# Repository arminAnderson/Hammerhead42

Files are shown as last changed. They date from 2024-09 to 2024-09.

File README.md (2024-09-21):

# Hammerhead42
42 key board with 24 degree angled sides with 3key support

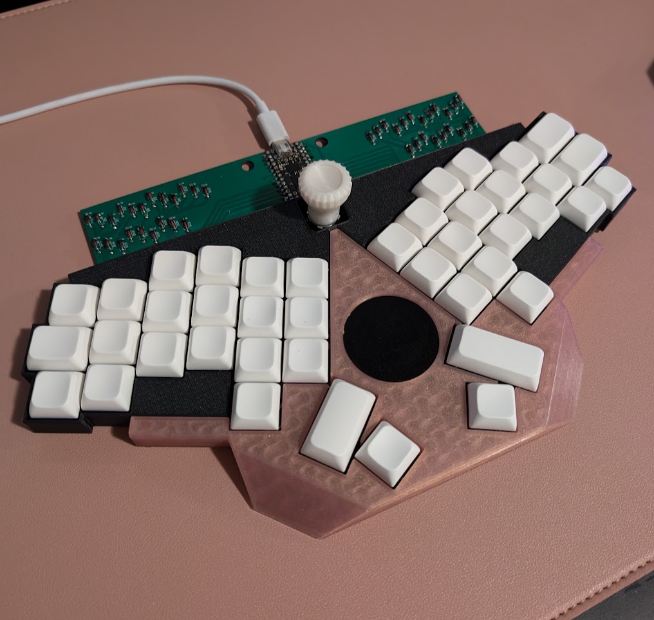
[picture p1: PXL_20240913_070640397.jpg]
Example


# Current required hardware
* M2 screws
* M2 threaded inserts (https://www.amazon.com/dp/B0D477R64K?ref=ppx_yo2ov_dt_b_fed_asin_title&th=1)
* RKJXT1F42001 (https://www.digikey.com/en/products/detail/alps-alpine/RKJXT1F42001/19529127, cap here: https://www.printables.com/model/1013994-rkjxt1f42001-cap)
* 40mm cirque touchpad (https://www.mouser.com/ProductDetail/Cirque/TM040040-2024-302?qs=wd5RIQLrsJgMzmw571gvDw%3D%3D)
* 4 wires (touchpad is handwired to a breakout)
* Helios or similar (https://keeb.supply/products/0xcb-helios)
* Rubber feet
* One set of 2u stabs for right hand side (optional)

# v0.9 (current)
* Now using PCB instead of handwire

# Fixes planned for 1.0
* Right now, the case uses printed washers to help pin the case to the pcb, and rubber feet on the bottom to keep the pcb off the desk. Originally I did this to keep the thickness as minimal as possible, but I'd like to design a 2 piece case with a bottom
* Some of the mounting holes for the case on the pcb are tenths of a mm off, which probably isn't even perceptible but I want to get those perfectly aligned 
* Cases without the RKJXT1F and/or trackpad
* A way to mount the trackpad without a full case
* Full build guide
* Multiple key configurations (all 1u, for example). Currently, the non-1u keys are
  * 1.25 tab
  * 1.5 \|
  * 1.5 enter
  * 1.75 shift (left thumb)
  * 2 space (right thumb)

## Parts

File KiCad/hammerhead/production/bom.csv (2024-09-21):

Designator | Footprint | Quantity | Value | LCSC Part #
D1, D10, D11, D12, D13, D14, D15, D16, D17, D18, D19, D2, D20, D21, D22, D23, D24, D25, D26, D27, D28, D29, D3, D30, D31, D32, D33, D34, D35, D36, D37, D38, D39, D4, D40, D41, D42, D5, D6, D7, D8, D9 | D_DO-35_SOD27_P7.62mm_Horizontal | 42 | 1N4148
J2 | PinHeader_1x04_P2.54mm_Vertical | 1 | Conn_01x04_Pin
S1 | RKJXT1F42001 | 1 | RKJXT1F42001
S2 | STAB_MX_2u | 1 | MX_stab
SW1, SW10, SW11, SW12, SW13, SW14, SW15, SW16, SW17, SW18, SW19, SW2, SW21, SW22, SW23, SW24, SW25, SW26, SW27, SW28, SW29, SW3, SW30, SW31, SW32, SW33, SW34, SW35, SW36, SW37, SW41, SW42, SW5, SW6, SW7, SW8, SW9 | SW_MX_1u | 37 | SW_Push
SW20, SW38 | SW_MX_1.75u | 2 | SW_Push
SW39, SW40 | SW_MX_1.5u | 2 | SW_Push
SW4 | SW_MX_1.25u | 1 | SW_Push

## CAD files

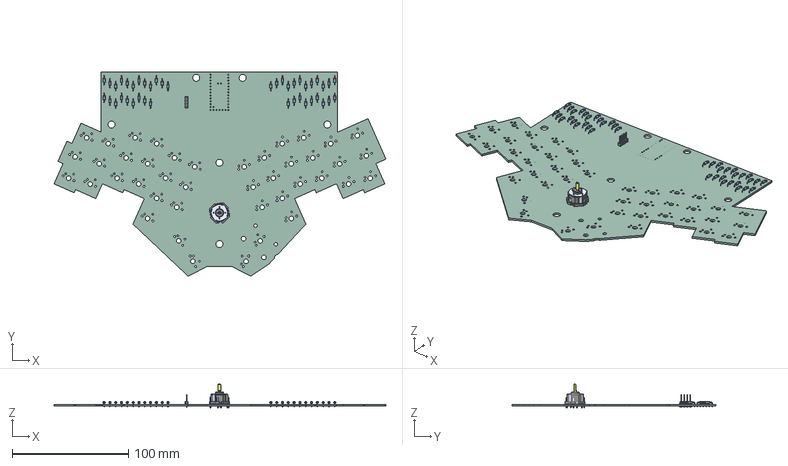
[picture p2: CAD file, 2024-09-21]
KiCad/hammerhead/hammerhead.step
285.8 x 176.0 x 20.6 mm
D_DO-35_SOD27_P7.62mm_Horizontal x 42
RKJXT1F42001
PinHeader_1x04_P254mm_Vertical
hammerhead_PCB

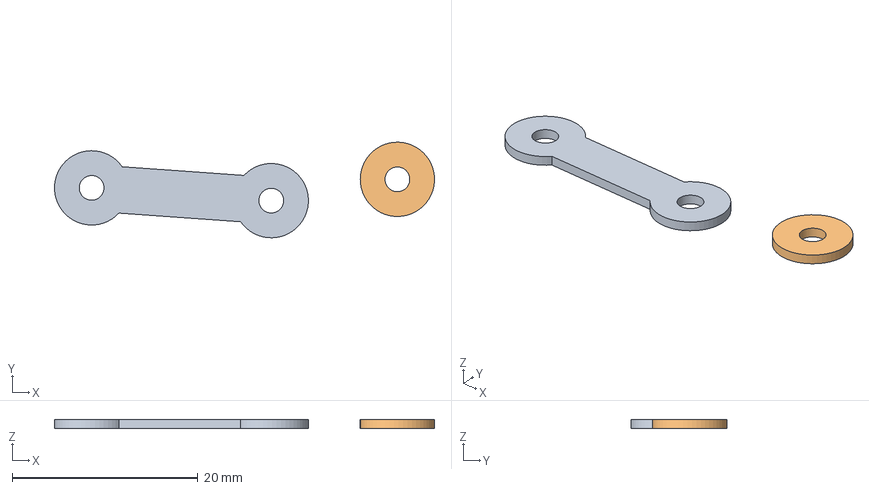
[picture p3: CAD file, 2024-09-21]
Models/printed_shims.step
40.9 x 10.3 x 1.00 mm

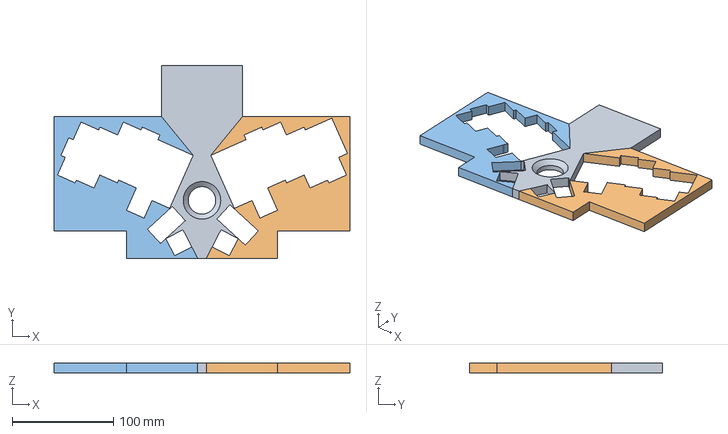
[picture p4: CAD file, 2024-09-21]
KiCad/hammerhead/hammerheadPCB v12.step
291.7 x 189.8 x 10.0 mm

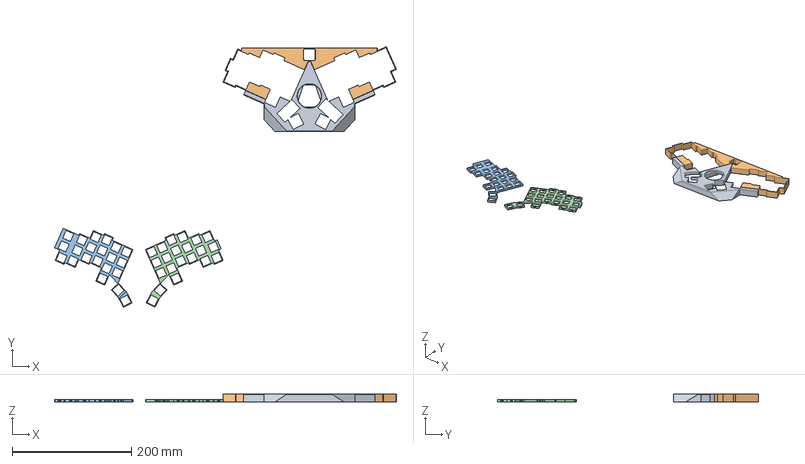
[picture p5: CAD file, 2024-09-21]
Models/case.step
572.5 x 436.3 x 13.6 mm

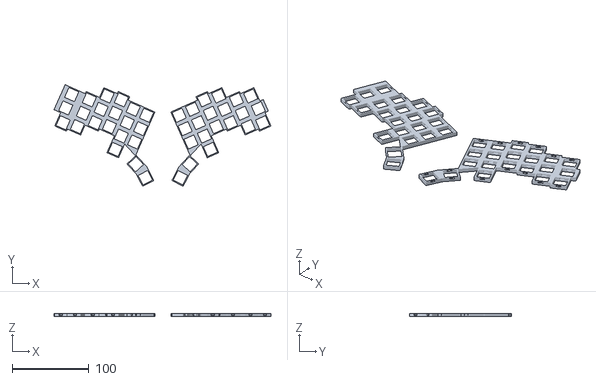
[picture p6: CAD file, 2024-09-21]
Models/plate.stl
282.5 x 132.3 x 4.00

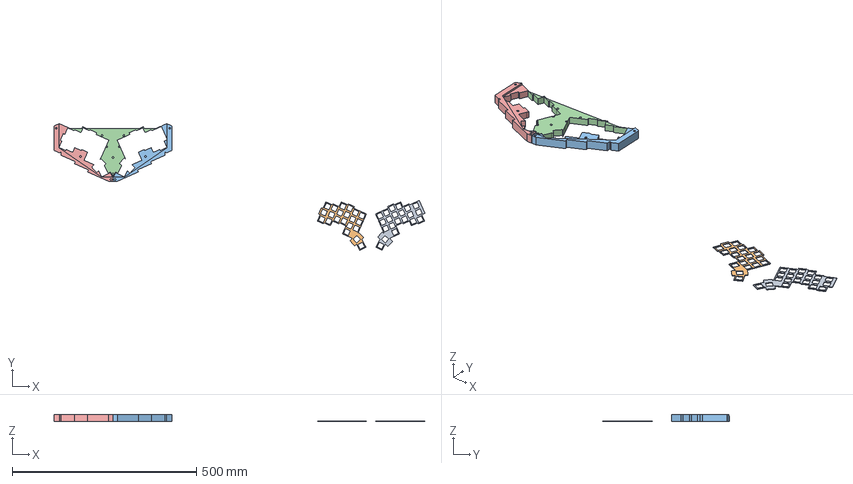
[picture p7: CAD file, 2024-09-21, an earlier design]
KiCad/hammerhead/hammerheadPCB v7.step
1006.7 x 344.0 x 18.0 mm

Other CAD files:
Models/plates.step
KiCad/hammerhead/hammerheadPCB v12.stl
Models/case.stl
Models/printed_shims.stl

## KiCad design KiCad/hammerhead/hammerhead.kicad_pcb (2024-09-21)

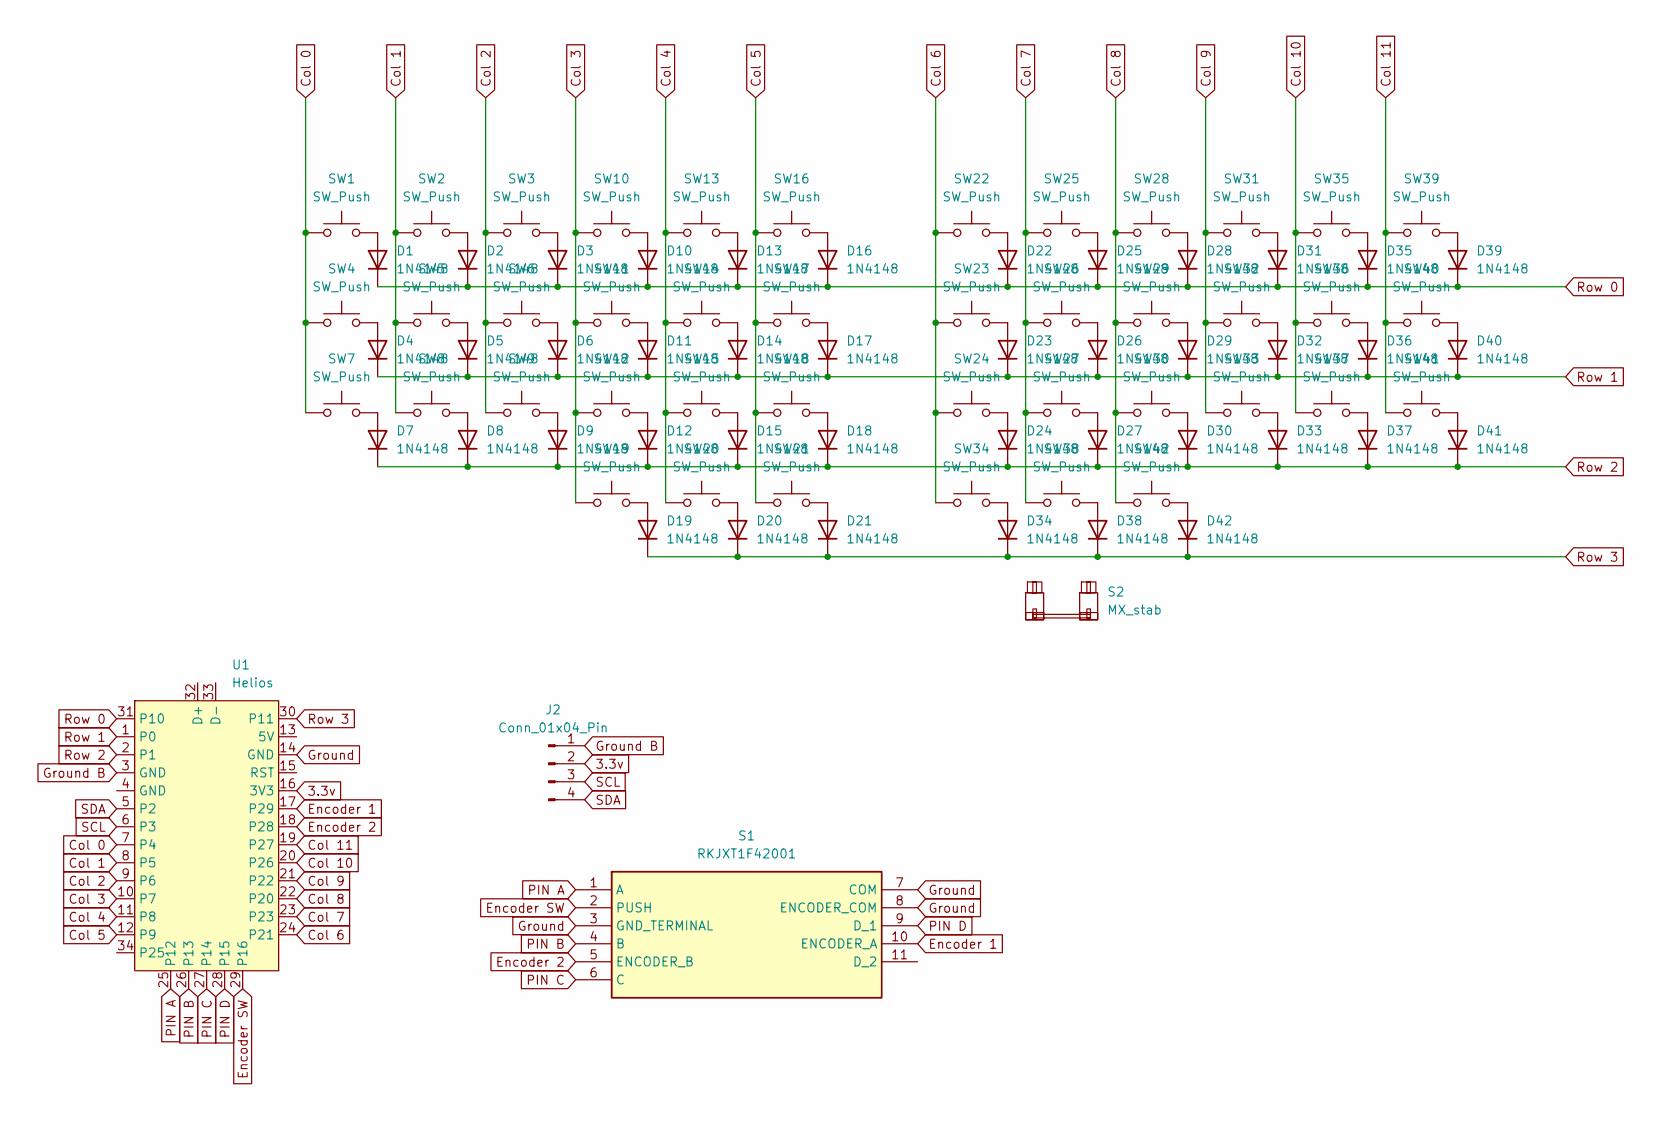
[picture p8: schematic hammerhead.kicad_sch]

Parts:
D1, D2, D3, D4, D5, D6, D7, D8, D9, D10, D11, D12, D13, D14, D15, D16, D17, D18, D19, D20, D21, D22, D23, D24, D25, D26, D27, D28, D29, D30, D31, D32, D33, D34, D35, D36, D37, D38, D39, D40, D41, D42: 1N4148; D_DO-35_SOD27_P7.62mm_Horizontal
J2: Conn_01x04_Pin; PinHeader_1x04_P2.54mm_Vertical
S1: RKJXT1F42001; Mouser Part Number 688-RKJXT1F42001
S2: MX_stab; STAB_MX_2u
SW1, SW2, SW3, SW5, SW6, SW7, SW8, SW9, SW10, SW11, SW12, SW13, SW14, SW15, SW16, SW17, SW18, SW19, SW21, SW22, SW23, SW24, SW25, SW26, SW27, SW28, SW29, SW30, SW31, SW32, SW33, SW34, SW35, SW36, SW37, SW41, SW42: SW_Push; SW_MX_1u
SW4: SW_Push; SW_MX_1.25u
SW20, SW38: SW_Push; SW_MX_1.75u
SW39, SW40: SW_Push; SW_MX_1.5u
U1: Helios; Helios_ACH

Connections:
3.3v: J2.2, U1.16 (3V3)
Col 0: SW1.1, SW4.1, SW7.1, U1.7 (P4)
Col 1: SW2.1, SW5.1, SW8.1, U1.8 (P5)
Col 2: SW3.1, SW6.1, SW9.1, U1.9 (P6)
Col 3: SW10.1, SW11.1, SW12.1, SW19.1, U1.10 (P7)
Col 4: SW13.1, SW14.1, SW15.1, SW20.1, U1.11 (P8)
Col 5: SW16.1, SW17.1, SW18.1, SW21.1, U1.12 (P9)
Col 6: SW22.1, SW23.1, SW24.1, SW34.1, U1.24 (P21)
Col 7: SW25.1, SW26.1, SW27.1, SW38.1, U1.23
Col 8: SW28.1, SW29.1, SW30.1, SW42.1, U1.22 (P20)
Col 9: SW31.1, SW32.1, SW33.1, U1.21 (P22)
Col 10: SW35.1, SW36.1, SW37.1, U1.20 (P26)
Col 11: SW39.1, SW40.1, SW41.1, U1.19 (P27)
Encoder 1: S1.10 (ENCODER_A), U1.17 (P29)
Encoder 2: S1.5 (ENCODER_B), U1.18 (P28)
Encoder SW: S1.2 (PUSH), U1.29 (P16)
Ground: S1.3 (GND_TERMINAL), S1.7 (COM), S1.8 (ENCODER_COM), U1.14 (GND)
Ground B: J2.1, U1.3 (GND)
unnamed: D1.2 (A), SW1.2
unnamed: D2.2 (A), SW2.2
unnamed: D3.2 (A), SW3.2
unnamed: D4.2 (A), SW4.2
unnamed: D5.2 (A), SW5.2
unnamed: D6.2 (A), SW6.2
unnamed: D7.2 (A), SW7.2
unnamed: D8.2 (A), SW8.2
unnamed: D9.2 (A), SW9.2
unnamed: D10.2 (A), SW10.2
unnamed: D11.2 (A), SW11.2
unnamed: D12.2 (A), SW12.2
unnamed: D13.2 (A), SW13.2
unnamed: D14.2 (A), SW14.2
unnamed: D15.2 (A), SW15.2
unnamed: D16.2 (A), SW16.2
unnamed: D17.2 (A), SW17.2
unnamed: D18.2 (A), SW18.2
unnamed: D19.2 (A), SW19.2
unnamed: D20.2 (A), SW20.2
unnamed: D21.2 (A), SW21.2
unnamed: D22.2 (A), SW22.2
unnamed: D23.2 (A), SW23.2
unnamed: D24.2 (A), SW24.2
unnamed: D25.2 (A), SW25.2
unnamed: D26.2 (A), SW26.2
unnamed: D27.2 (A), SW27.2
unnamed: D28.2 (A), SW28.2
unnamed: D29.2 (A), SW29.2
unnamed: D30.2 (A), SW30.2
unnamed: D31.2 (A), SW31.2
unnamed: D32.2 (A), SW32.2
unnamed: D33.2 (A), SW33.2
unnamed: D34.2 (A), SW34.2
unnamed: D35.2 (A), SW35.2
unnamed: D36.2 (A), SW36.2
unnamed: D37.2 (A), SW37.2
unnamed: D38.2 (A), SW38.2
unnamed: D39.2 (A), SW39.2
unnamed: D40.2 (A), SW40.2
unnamed: D41.2 (A), SW41.2
unnamed: D42.2 (A), SW42.2
PIN A: S1.1 (A), U1.25 (P12)
PIN B: S1.4 (B), U1.26 (P13)
PIN C: S1.6 (C), U1.27 (P14)
PIN D: S1.9 (D_1), U1.28 (P15)
Row 0: D1.1 (K), D2.1 (K), D3.1 (K), D10.1 (K), D13.1 (K), D16.1 (K), D22.1 (K), D25.1 (K), D28.1 (K), D31.1 (K), D35.1 (K), D39.1 (K), U1.31 (P10)
Row 1: D4.1 (K), D5.1 (K), D6.1 (K), D11.1 (K), D14.1 (K), D17.1 (K), D23.1 (K), D26.1 (K), D29.1 (K), D32.1 (K), D36.1 (K), D40.1 (K), U1.1 (P0)
Row 2: D7.1 (K), D8.1 (K), D9.1 (K), D12.1 (K), D15.1 (K), D18.1 (K), D24.1 (K), D27.1 (K), D30.1 (K), D33.1 (K), D37.1 (K), D41.1 (K), U1.2 (P1)
Row 3: D19.1 (K), D20.1 (K), D21.1 (K), D34.1 (K), D38.1 (K), D42.1 (K), U1.30 (P11)
SCL: J2.3, U1.6 (P3)
SDA: J2.4, U1.5 (P2)

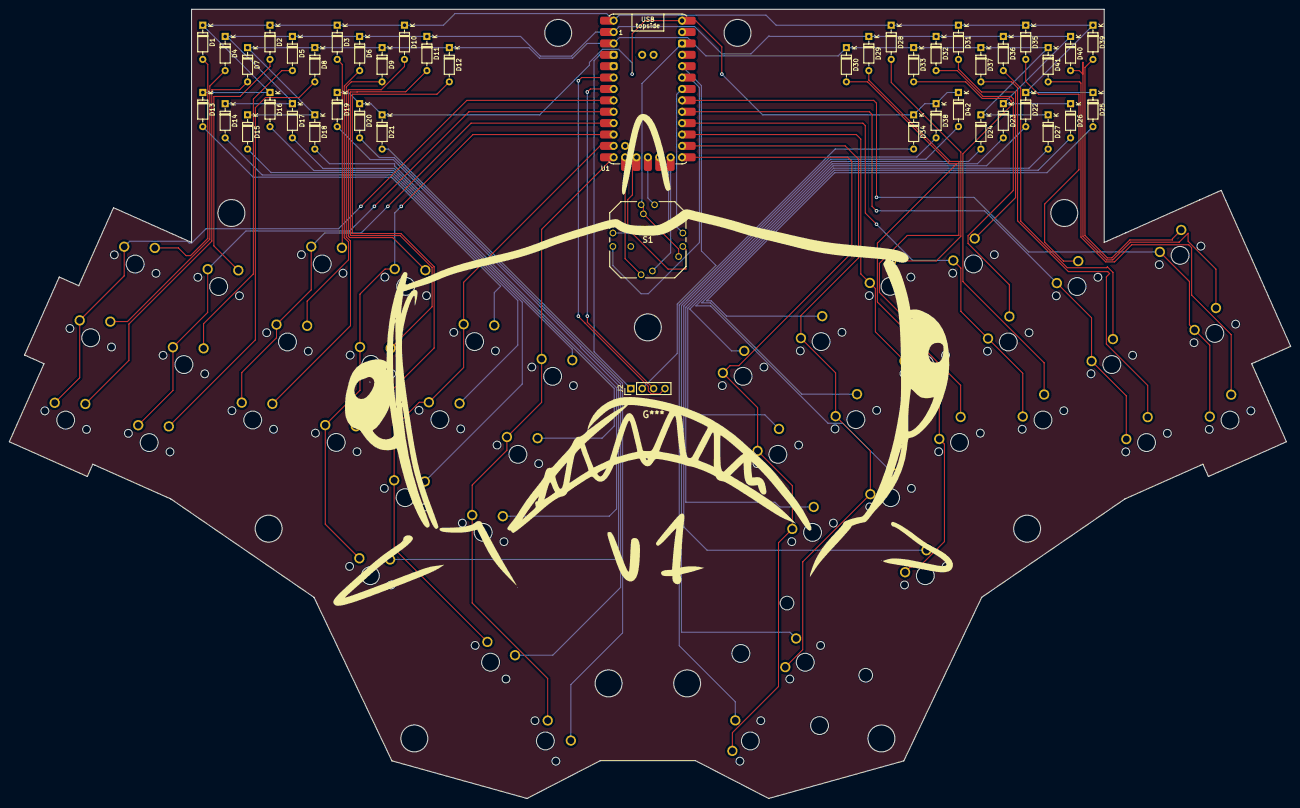
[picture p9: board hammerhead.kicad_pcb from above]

Board: 2 copper layers, 285.8 x 176.0 mm, 88 parts (0 on the bottom side), 70 nets.

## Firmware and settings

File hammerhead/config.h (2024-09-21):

// Copyright 2024 arminkanderson (@arminkanderson)
// SPDX-License-Identifier: GPL-2.0-or-later

#pragma once

#define ENCODERS_PAD_A { GP29 }
#define ENCODERS_PAD_B { GP28 }
#define ENCODER_RESOLUTIONS { 2 }

#define I2C_DRIVER I2CD1

#define I2C1_SDA_PIN GP2
#define I2C1_SCL_PIN GP3

#define POINTING_DEVICE_ROTATION_90 true
#define CIRQUE_PINNACLE_TAP_ENABLE true

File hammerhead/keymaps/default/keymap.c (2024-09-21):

// Copyright 2023 QMK
// SPDX-License-Identifier: GPL-2.0-or-later

#include QMK_KEYBOARD_H

const uint16_t PROGMEM keymaps[][MATRIX_ROWS][MATRIX_COLS] = { 
    [0] = LAYOUT( 
		KC_ESC,         KC_Q,           KC_W,           KC_E,                   KC_R,                   KC_T,                       KC_Y,           KC_U,           KC_I,                   KC_O,                   KC_P,           KC_BACKSLASH,
		KC_TAB,         KC_A,           KC_S,           KC_D,                   KC_F,                   KC_G,                       KC_H,           KC_J,           KC_K,                   KC_L,                   KC_SCLN,        KC_ENTER,           
		KC_LEFT_ALT,    KC_Z,           KC_X,           KC_C,                   KC_V,                   KC_B,                       KC_N,           KC_M,           KC_COMM,                KC_DOT,                 KC_SLSH,        KC_RGUI,            
		                                                KC_LEFT_CTRL,           KC_LEFT_SHIFT,          MO(2),                      MO(1),          KC_SPC,         KC_BACKSPACE                      
    ),
 
    [1] = LAYOUT(
        KC_GRAVE,       KC_EXCLAIM,     KC_AT,          KC_HASH,                KC_DOLLAR,              KC_PERCENT,                 KC_CIRCUMFLEX,  KC_UNDERSCORE,  KC_ASTERISK,            KC_LEFT_PAREN,          KC_RIGHT_PAREN, KC_AMPERSAND,      
        _______,        KC_1,           KC_2,           KC_3,                   KC_4,                   KC_5,                       KC_6,           KC_7,           KC_8,                   KC_9,                   KC_0,           KC_QUOTE,             
        KC_CAPS_LOCK,   KC_NO,          KC_NO,          KC_NO,                  KC_NO,                  KC_NO,                      KC_NO,          KC_NO,          KC_NO,                  KC_NO,                  KC_NO,          _______,           
                                                        _______,                _______,                _______,                    _______,        _______,        KC_DELETE
    ),

    [2] = LAYOUT(
        _______,        _______,        _______,        KC_LEFT_PAREN,          KC_RIGHT_PAREN,         _______,                    _______,        _______,        _______,                _______,                _______,        _______,      
        _______,        _______,        _______,        KC_LEFT_CURLY_BRACE,    KC_RIGHT_CURLY_BRACE,   _______,                    _______,        KC_MINUS,       KC_PLUS,                KC_EQUAL,               _______,        _______,             
        _______,        _______,        _______,        KC_LEFT_BRACKET,        KC_RIGHT_BRACKET,       _______,                    _______,        KC_EXCLAIM,     KC_LEFT_ANGLE_BRACKET,  KC_RIGHT_ANGLE_BRACKET, _______,        _______,           
                                                        KC_BTN2,                _______,                _______,                    _______,        _______,        _______
    )  
};

struct PinStates
{
    bool a, b, c, d, center;
} states;

void keyboard_pre_init_user(void) 
{
    pointing_device_set_cpi(1024/4);

    gpio_set_pin_input_high(GP12);
    gpio_set_pin_input_high(GP13);
    gpio_set_pin_input_high(GP14);
    gpio_set_pin_input_high(GP15);
    gpio_set_pin_input_high(GP16);

    states.a = false;
    states.b = false;
    states.c = false;
    states.d = false;
    states.center = false;
}

#if defined(ENCODER_MAP_ENABLE)
const uint16_t PROGMEM encoder_map[][NUM_ENCODERS][NUM_DIRECTIONS] = {
    [0] = { ENCODER_CCW_CW(KC_VOLU, KC_VOLD)  },
    [1] = { ENCODER_CCW_CW(KC_MEDIA_NEXT_TRACK, KC_MEDIA_PREV_TRACK)  },
    [2] = { ENCODER_CCW_CW(KC_WH_U, KC_WH_D)  }
};
#endif


static bool pinA = false;
static bool pinB = false;
static bool pinC = false;
static bool pinD = false;
static bool center = false;

void housekeeping_task_user(void) 
{
    pinA   = gpio_read_pin(GP12);
    pinB   = gpio_read_pin(GP13);
    pinC   = gpio_read_pin(GP14);
    pinD   = gpio_read_pin(GP15);
    center = gpio_read_pin(GP16);

    if(pinA != states.a)
    {
        if(!pinA) { register_code(KC_UP); }
        else { unregister_code(KC_UP); }
        states.a = pinA;
    }

    if(pinB != states.b)
    {
        if(!pinB) { register_code(KC_LEFT); }
        else { unregister_code(KC_LEFT); }
        states.b = pinB;
    }

    if(pinC != states.c)
    {
        if(!pinC) { register_code(KC_DOWN); }
        else { unregister_code(KC_DOWN); }
        states.c = pinC;
    }

    if(pinD != states.d)
    {
        if(!pinD) { register_code(KC_RIGHT); }
        else { unregister_code(KC_RIGHT); }
        states.d = pinD;
    }

    if(pinD != states.d)
    {
        if(!pinD) { register_code(KC_RIGHT); }
        else { unregister_code(KC_RIGHT); }
        states.d = pinD;
    }

    if(pinA && pinB && pinC && pinD)
    {
        if(center != states.center)
        {
            if(!center) { register_code(KC_MEDIA_PLAY_PAUSE); }
            else { unregister_code(KC_MEDIA_PLAY_PAUSE); }
            states.center = center;
        }
    }
}
